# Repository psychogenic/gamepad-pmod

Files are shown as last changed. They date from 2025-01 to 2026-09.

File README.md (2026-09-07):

# Gamepad PMOD
CH32V003-based 2xSNES-compatible controller interface PMOD

Copyright (C) 2025 Pat Deegan, [psychogenic.com](https://psychogenic.com)

Released as free and open source software under the terms of the GPL (see [LICENSE](./LICENSE))

## Overview 

This simple module allows 1 or 2 SNES controllers to report their state over 3 pins, and is used with my SNES PMOD.  Here's the first prototype:

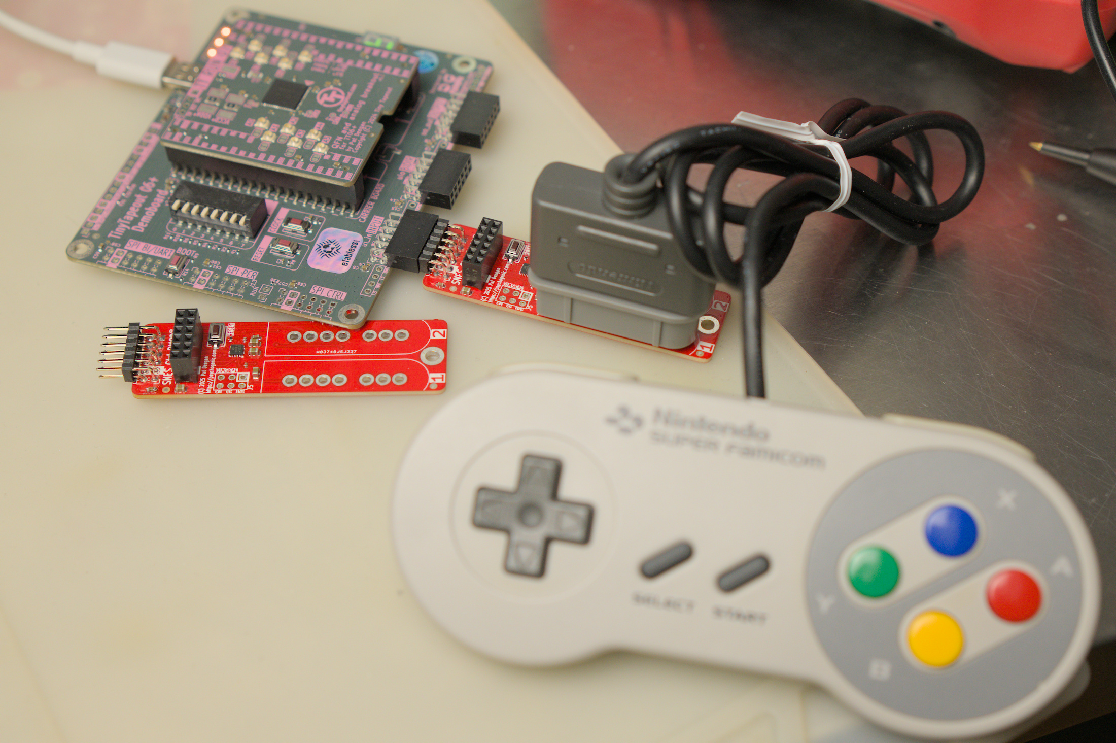
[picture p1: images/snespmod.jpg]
snes pmod


It is a variation on the SNES controller protocol that automatically polls the controllers and reports back values.  The main differences are that the data may be sampled on the rising edge of the clock and the latch happens at the end so it acts like a SIPO (serial in, parallel out) shift register and you can just save the values whenever you see the pulse.  

This allows for using the controllers as read-only devices (i.e. using only input pins on your side) and will send all values in a single transaction (e.g. 24 bits of data in one burst for two controllers).

It may be easily configured (by editing the [config definitions file](src/ch32gamepad_config.h)) to specify:

  * whether to report continuously, only on change and/or with a maximum interval between reports (e.g. only on change but at least every 2 seconds, as is the default configuration);
  
  * the number of controllers (1 or 2);
  
  * the PMOD pins to report back on;
  
  * the bitrate at which these reports are sent;

## Using the gamepad in projects

A [verilog module](verilog/) is provided that makes inclusion in projects simple.  Include the [gamepad_pmod.v](verilog/gamepad_pmod.v) source file in your build and, somewhere in your project, instantiate one of 

	* gamepad_pmod_dual -- to support two controllers, or
	
	* gamepad_pmod_single -- to only support a single controller

You then feed the gamepad module the input data, clock and latch from the outside world and from there you receive information about which buttons are pressed at any time.  

More information and basic samples are in the [verilog directory](verilog/).

A nice example of an implementation using this module is Uri's [2048 game](https://github.com/urish/tt10-2048-game).

## Reading the gamepad from micropython

Though it is designed for use with FPGA/ASIC projects, the reports from controller(s) may also be read on an RP2040 (e.g. the [Tiny Tapeout demoboard](https://github.com/tinyTapeout/tt-demo-pcb)) using code like the sample in [gamepad_reader.py](micropython/gamepad_reader.py).

## Hardware

This code all runs on a simple PMOD that's little more than a CH32V003 and headers to connect to the controllers and PMOD.

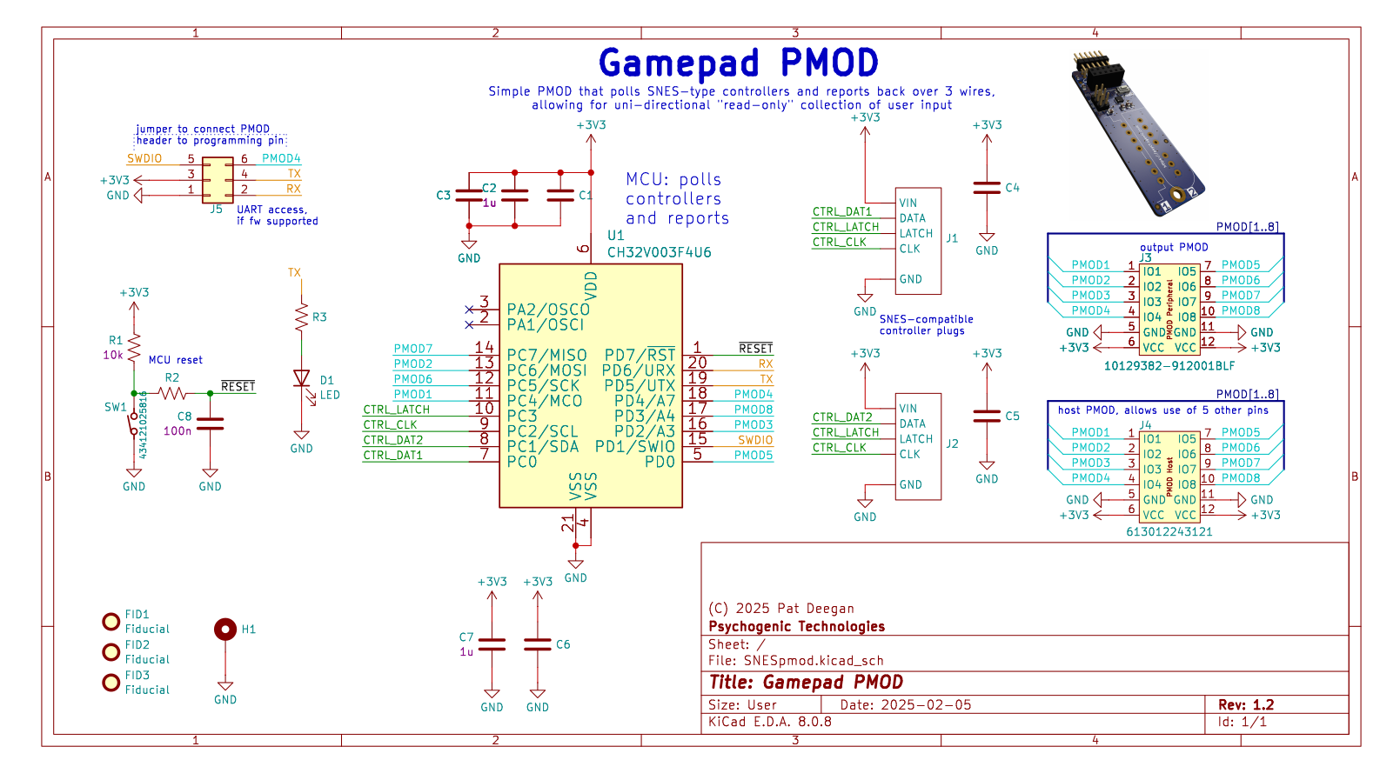
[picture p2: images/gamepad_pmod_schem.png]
schematic


The CH32V polls the controllers as per the standard method for these controllers and, on change or timeout, shoots data out through the peripheral PMOD header, as described in "protocol" below.

It also includes:

  * a PMOD host header, so you could in theory leverage the 5 unused input pins using another PMOD
  
  * an extra 2x3 100 mil header that allows you to jumper the PMOD IO4 into the SWDIO pin, to allow for programming through the PMOD header.
  
The complete project is available under [hardware/GamepadPMOD](hardware/GamepadPMOD).

## Protocol

Reports are sent in the following manner, by default over 3 pins:

  * latch; 
  
  * clock; and
  
  * data

Sample waveform, one controller disconnected, the other holding 3 buttons:

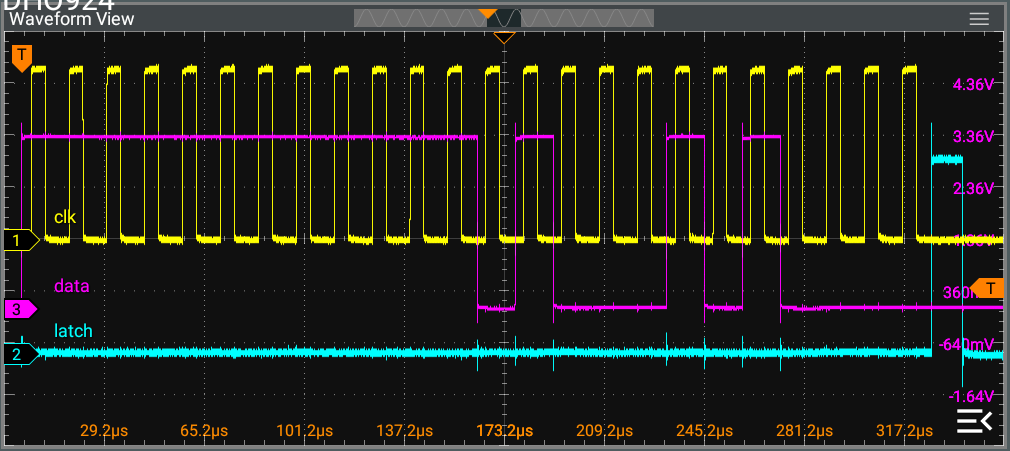
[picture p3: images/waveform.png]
report waveform


A disconnected controller reports all 1s, which includes impossible combinations (e.g. up and down at the same time), and lets us detect controller presence.

Data will be asserted on the data line prior to the clock going high and remain valid past when the clock goes low.  After all bits are sent, latch pulses high.

Each bit will be sent in turn, for each controller, in the following order:

  1. B
  
  2. Y
  
  3. select
  
  4. start
  
  5. up
  
  6. down
  
  7. left
  
  8. right
  
  9. A
  
  10. X
  
  11. L
  
  12. R

With a HIGH value indicating the relevant button is pressed.

## Default TT Configuration

The default setup we'll use for [Tiny Tapeout](https://tinytapeout.com) is:

  *  100kHz clock rate, so that even slowish projects can leverage the input;
  
  *  Latch on PMOD IO5 (*ui_in[4]* on the demoboards, PMODs _aren't_ 0-indexed);
  
  *  Clock on PMOD IO6 (*ui_in[5]*);
  
  *  Data on PMOD IO7 (*ui_in[6]*);
  
  *  2 controllers, i.e. 24 bits of data before the latch pulses; and
  
  *  report-on-change but with a maximum interval between bursts of 1 second (minimum interval is about 1.66ms, or a 600Hz rate for reports, like the SNES console)

### Note on latency and clock domains

Though the SNES consoles only polled at 60Hz, nicely sync'ed to the framerate, if you're a speedrunner you could hit some issues if we do the same, as the PMOD isn't synchronized with the system clock.

After discussion with the community and tests with both el-cheapo chinese controllers and an old famicom thing from the 90s, I'm 10x-ing the controller polling rate to 600Hz.  This doesn't actually impact the rate at which the controllers are clocked, it's just that it happens more often and doesn't seem to cause issue.

From the actual SNES controller perspective, the interaction looks like this:

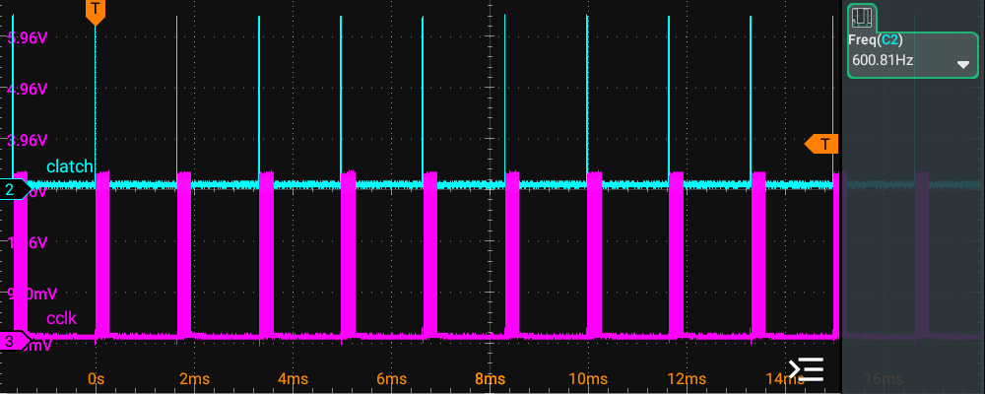
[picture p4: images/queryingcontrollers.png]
snes controller polling


You can see that, on that side, the latch signal comes before the burst of clocking and it's being polled at just around 600Hz.

Since the clocks in projects are independent from the moment at which reports can arrive, its best to do some cleaning for clock domain crossing to ensure stability.

Best and easiest thing is just to use the [gaming_pmod sample module](https://github.com/psychogenic/vga-playground/blob/gaming-pmod/src/examples/gaming/gaming_pmod.v#L109), which handles this.

If you're looking to roll your own, in verilog this would look like classic synchronizer patterns, e.g.

```
reg [1:0] pmod_data_sync;
always @(posedge clk) begin
  if (~rst_n) begin
    pmod_data_sync  <= 2'b0;
  end else begin
    pmod_data_sync  <= {pmod_data_sync[0], pmod_data};
  end
end
```

Whereas with Amaranth, it's little more than using the [FFSynchronizer](https://amaranth-lang.org/docs/amaranth/v0.3/stdlib/cdc.html)

```
FFSynchronizer(i=pmod_data, o=pmod_data_sync)
```

## Building

A selection of pre-compiled firmware is available in [firmware](./firmware), but you may want to build yourself...

To do so, you'll need the awesome [ch32v003fun](https://github.com/cnlohr/ch32v003fun) SDK, by [cnlohr](https://github.com/cnlohr), which is already included here as a submodule.  To ensure you have that, you can do

```
git submodule update --init --recursive
```

from the top level directory.

Then simply (optionally) hook-up a supported programmed to the target module and

```
cd src
make
```

That should be it.

## Updating firmware

The CH32V firmware may be updated using a suitable programmer.  However, to assist the production run and to make future updates easy I updated the pico_ch32v003_prog to use less memory and burn firmware.

The fork and a sample using it is available on [gamepad-update](https://github.com/psychogenic/gamepad-update/tree/main/src).

Adding a jumper between the two top pins on the 6-pin header, between PRJ and SWIO:

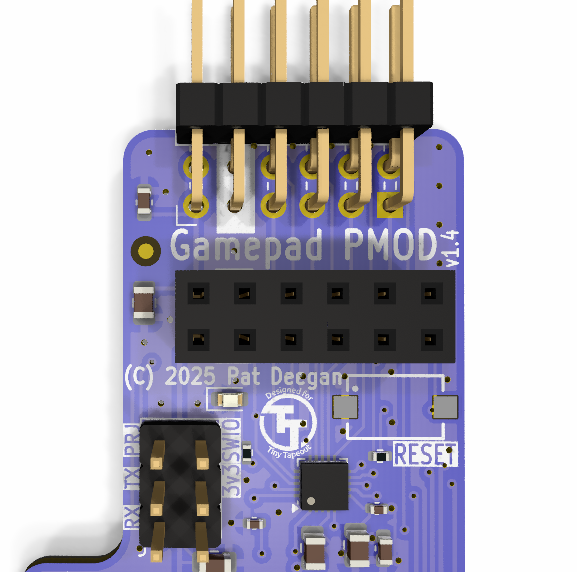
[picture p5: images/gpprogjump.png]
programming header


will connect PMOD IO4 to the programming pin and allow the RP2040 on the demoboard to write new firmware.

## Assembly

These controller connectors aren't actually meant to be used this way.  In order to provide a bit of stability, we 3D print little feet:

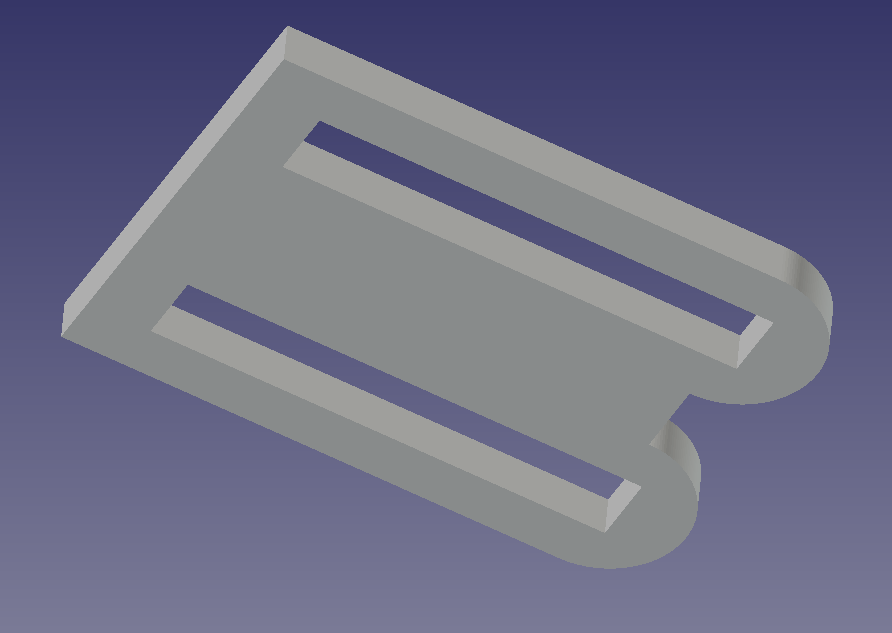
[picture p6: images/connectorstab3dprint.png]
stabilizer foot


The STL file for this is [hardware/gamepad-footstabv1p0-tol2.stl](./hardware/gamepad-footstabv1p0-tol2.stl)

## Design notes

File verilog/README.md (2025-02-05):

# Gamepad PMOD verilog module

This module provides plug & play support for the gamepad pmod in your projects

Include the [gamepad_pmod.v](gamepad_pmod.v) source file in your build and, somewhere in your project, instantiate one of 

	* gamepad_pmod_dual -- to support one or two controllers, or
	
	* gamepad_pmod_single -- to only support a single controller

You then feed the gamepad module the input data, clock and latch from the outside world and from there you receive information about which buttons are pressed at any time.  The module outputs split up the buttons such that they have reasonable names and they will be HIGH as long as the button in question is held pressed by the user.

## single controller support

If you want to save on bits, you may use the `gamepad_pmod_single`.  This only latches in the last 12 bits of data, so might give you a little bit of space saving in term of flops but you'll be losing data for one player if two controllers are physically connected.

It provides this interface

```
module gamepad_pmod_single (
    input wire rst_n,
    input wire clk,
    input wire pmod_data,
    input wire pmod_clk,
    input wire pmod_latch,

    output wire b,
    output wire y,
    output wire select,
    output wire start,
    output wire up,
    output wire down,
    output wire left,
    output wire right,
    output wire a,
    output wire x,
    output wire l,
    output wire r,
    output wire is_present
);
```

Other than the clock and reset, it takes in three wires from the PMOD for data, clock and latch.  The outputs are split as individual bits, `start`, `left`, `right` etc.  These will remain HIGH so long as the button is held.

In addition to the standard controller buttons, there is an `is_present` field to let you know whether there's a controller connected.

## dual controller support

At the cost of shuffling 12 extra bits around, you can support up to two controllers using `gamepad_pmod_dual`.  This module takes the same inputs as the single version, and basically provides the same API, but instead of single wires for the buttons, each is two bits wide, so you get the status of each controller indexed within (e.g. if  `is_present[0]` and `is_present[1]` are both HIGH, you have two controllers connected).

The module API is thus:

```
module gamepad_pmod_dual (
    input wire rst_n,
    input wire clk,
    input wire pmod_data,
    input wire pmod_clk,
    input wire pmod_latch,

    output wire [1:0] b,
    output wire [1:0] y,
    output wire [1:0] select,
    output wire [1:0] start,
    output wire [1:0] up,
    output wire [1:0] down,
    output wire [1:0] left,
    output wire [1:0] right,
    output wire [1:0] a,
    output wire [1:0] x,
    output wire [1:0] l,
    output wire [1:0] r,
    output wire [1:0] is_present
);
```
 
## Including in a project

Including in a project is just a question of instantiating a module to wire it up and then acting according to button presses reported.  It might look something like:

```
module my_top (
    input  wire [7:0] ui_in,    // Dedicated inputs
    output wire [7:0] uo_out,   // Dedicated outputs
    input  wire [7:0] uio_in,   // IOs: Input path
    output wire [7:0] uio_out,  // IOs: Output path
    output wire [7:0] uio_oe,   // IOs: Enable path (active high: 0=input, 1=output)
    input  wire       ena,      // always 1 when the design is powered, so you can ignore it
    input  wire       clk,      // clock
    input  wire       rst_n     // reset_n - low to reset
);

  // Gamepad Pmod support
  wire gamepad_pmod_latch = ui_in[4];
  wire gamepad_pmod_clk = ui_in[5];
  wire gamepad_pmod_data = ui_in[6];
  wire gamepad_is_present;
  wire gamepad_left;
  wire gamepad_right;
  wire gamepad_up;
  wire gamepad_down;
  wire gamepad_start;
  wire gamepad_select;

  gamepad_pmod_single gamepad_pmod (
      // Inputs:
      .clk(clk),
      .rst_n(rst_n),
      .pmod_latch(gamepad_pmod_latch),
      .pmod_clk(gamepad_pmod_clk),
      .pmod_data(gamepad_pmod_data),

      // Outputs:
      .is_present(gamepad_is_present),
      .left(gamepad_left),
      .right(gamepad_right),
      .up(gamepad_up),
      .down(gamepad_down),
      .start(gamepad_start),
      .select(gamepad_select)
  );
  // do things when buttons are pressed and gamepad_* go high.
  
endmodule

```

A nice example of an implementation using this module is Uri's [2048 game](https://github.com/urish/tt10-2048-game).

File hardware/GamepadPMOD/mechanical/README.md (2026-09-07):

# Dual straight-SNES connector gap filler

`dual_snes_connector_gap_filler.stl` is one consolidated two-piece set that
supports **both** straight SNES connectors on one Gamepad PMOD.

## Measured fit

The dimensions come from `SNES_Connector_Straight_Master_Assy.stp`, which
matches the board's seven-pin 4/4/4/6.5/4/4 mm pitch:

| Feature | STEP Z | Result |
|---|---:|---:|
| PCB seating datum / pedestal bottom | -14.60 mm | — |
| Broad housing underside | -11.40 mm | — |
| Nominal housing-to-PCB gap | — | **3.20 mm** |
| Filler with vertical clearance | — | **3.10 mm** |

The matching
[vertical KiCad footprint](https://github.com/shuki25/kicad-custom-library/blob/master/footprints/SNES_Controller_Port_Vertical.kicad_mod)
applies a +14.60 mm Z offset to the STEP model. This places the pedestal
bottom at the PCB top surface and confirms the mounting datum used above.

The earlier 0.50 mm estimate from a different right-angle connector model does
not apply to this straight connector.

## Design and installation

Each connector's central semistadium-shaped pedestal reaches the PCB, leaving
a 3.20 mm-high ring-shaped cavity under the wider housing. The filler reproduces
the STEP model's exact outer and pedestal profiles with 0.15 mm horizontal
clearance. Matching halves for J1 and J2 are joined across the 4.50 mm space
between their housings by a bridge spanning the complete **32.25 mm straight
section** of the support profile. The result is split along the connector
pin-row direction into front and rear consolidated pieces. The two bridge
sections meet at the split without overlap, retaining post-assembly
installation while giving each half the widest possible load path.

Print flat without supports. Insert one half from each long side of the
connector until its inner profile seats around the central pedestal. A small
spot of flexible adhesive can retain a loose fit; keep adhesive away from
solder joints. Confirm the 3.20 mm gap on a production connector before batch
printing because STEP models do not define manufacturing tolerance.

## Files

- `dual_snes_connector_gap_filler.FCStd` — consolidated FreeCAD model
- `dual_snes_connector_gap_filler.step` — two-piece dual-connector solid
- `dual_snes_connector_gap_filler.stl` — one complete set per PCB
- `dual_snes_connector_gap_filler_kicad.step` — J1-local KiCad model
- `dual_snes_connector_gap_filler.py` — FreeCAD generator
- `GamepadPMOD_board.step` — PCB exported from the Elecrow branch
- `GamepadPMOD_dual_connector_assembly.FCStd` — visual fit assembly
- `GamepadPMOD_dual_connector_assembly.step` — portable assembly
- `GamepadPMOD_dual_connector_assembly.png` — top verification render
- `GamepadPMOD_dual_connector_assembly_side.png` — gap/profile render
- `render_assembly.ps1` — regenerate all models and renders

The design dimensions are collected at the top of the generator and recorded
in the `.FCStd` `Parameters` spreadsheet. Edit the generator and run:

```powershell
& 'C:\Program Files\FreeCAD 1.0\bin\freecadcmd.exe' dual_snes_connector_gap_filler.py
```

The visual assembly uses the Elecrow branch placements J1 `(22.50, 61.37,
-90°)` and J2 `(39.00, 61.37, -90°)`, the supplied connector STEP, and the
KiCad-exported board STEP. The board also references the connector STEP on J1
and J2 and the J1-local dual filler STEP, so KiCad's native 3D renderer checks
the same placements used by fabrication:

```powershell
.\render_assembly.ps1
```

The script exports the fully populated KiCad STEP and verifies that the STEP
pin centres exactly match all 14 PCB drills:

| Connector | Pin-centre X | Pin-centre Y |
|---|---:|---|
| J1 | 22.50 mm | 61.37, 65.37, 69.37, 73.37, 79.87, 83.87, 87.87 mm |
| J2 | 39.00 mm | 61.37, 65.37, 69.37, 73.37, 79.87, 83.87, 87.87 mm |

It also rejects filler-to-PCB or filler-to-connector intersections.

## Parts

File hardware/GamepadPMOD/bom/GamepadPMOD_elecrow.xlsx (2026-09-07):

*Reference | *Manufacturer Part number | *QTY | *Original | Description | Purchase Link
C1, C4, C5, C6 | CL21A106KOQNNNE | 4 |  | 10u/35V | https://www.digikey.com.au/en/products/result?keywords=CL21A106KOQNNNE
C2, C7 | CL10A105KB8NNNC | 2 |  | 1u | https://www.digikey.com.au/en/products/result?keywords=CL10A105KB8NNNC
C3, C8 | CL05B104KO5NNNC | 2 |  | 100n | https://www.digikey.com.au/en/products/result?keywords=CL05B104KO5NNNC
D1 | APT1608SURCK | 1 |  | Red LED, 630 nm, 0603 (1608 metric) | https://www.digikey.com.au/en/products/detail/kingbright/APT1608SURCK/386438
J1, J2 |  | 2 |  | SFC connector VERT
J3 | 10129382-912001BLF | 1 |  | 10129382-912001BLF | https://www.digikey.com.au/en/products/result?keywords=10129382-912001BLF
J4 | 613012243121 | 1 |  | 613012243121 | https://www.digikey.com.au/en/products/result?keywords=613012243121
J5 |  | 1 |  | Conn_02x03_Odd_Even
R1 | RC0402FR-0710KL | 1 |  | 10k | https://www.digikey.com.au/en/products/result?keywords=RC0402FR-0710KL
R2 | RC0402FR-071KL | 1 |  | 1k | https://www.digikey.com.au/en/products/result?keywords=RC0402FR-071KL
R3 | RC0402FR-07200RL | 1 |  | 200R | https://www.digikey.com.au/en/products/result?keywords=RC0402FR-07200RL
SW1 | 434121025816 | 1 |  | 434121025816 | https://www.digikey.com.au/en/products/result?keywords=434121025816
U1 | CH32V003F4U6 | 1 |  | CH32V003F4U6 | https://www.digikey.com.au/en/products/result?keywords=CH32V003F4U6

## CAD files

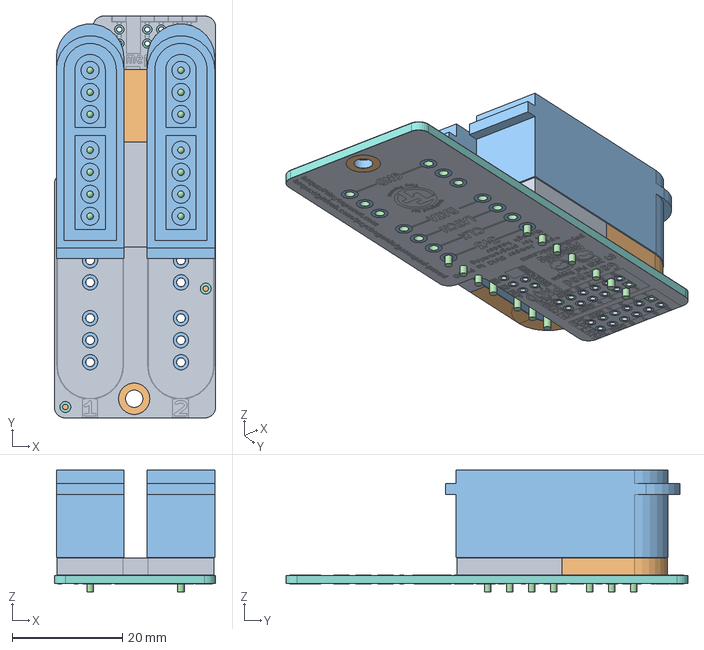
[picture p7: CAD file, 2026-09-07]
hardware/GamepadPMOD/mechanical/GamepadPMOD_dual_connector_assembly.step
29.3 x 73.0 x 22.1 mm

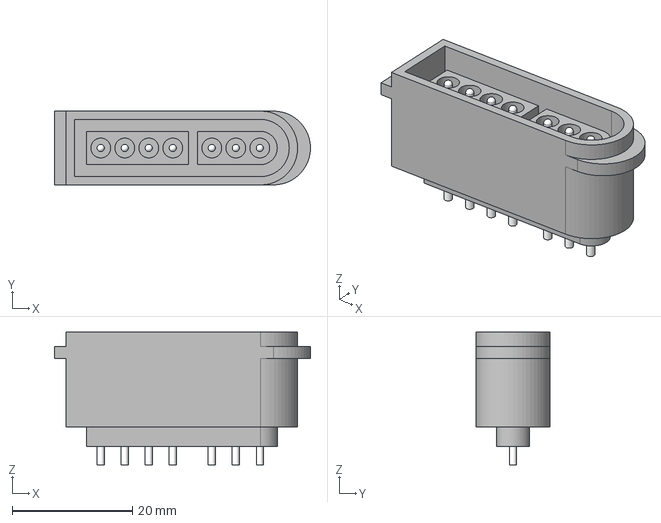
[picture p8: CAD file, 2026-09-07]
hardware/GamepadPMOD/mechanical/SNES_Connector_Straight_Master_Assy.stp
42.6 x 12.3 x 22.1 mm

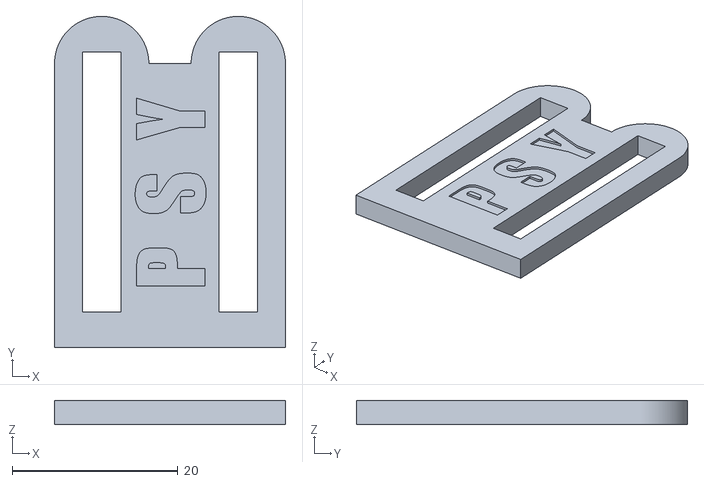
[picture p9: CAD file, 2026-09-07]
hardware/gamepad-footstabv1p0-tol2.stl
27.9 x 40.0 x 2.90

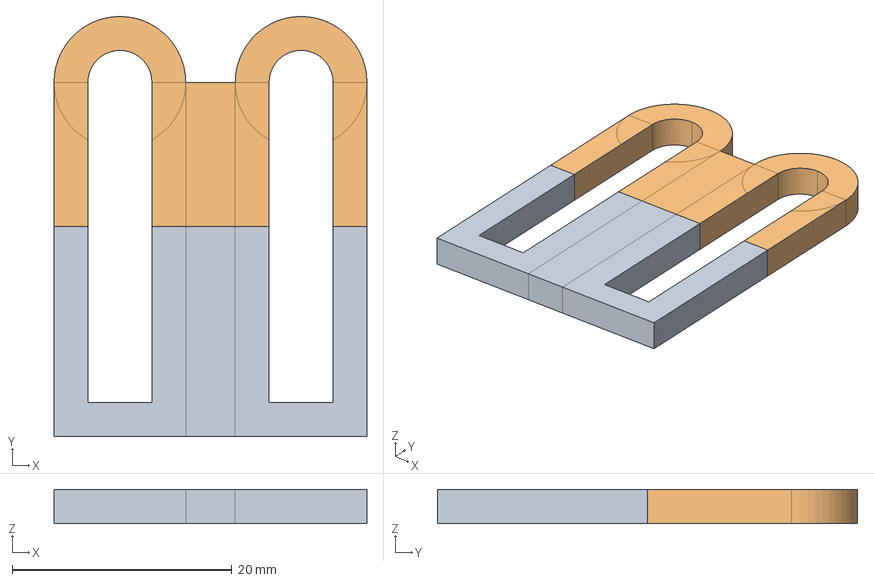
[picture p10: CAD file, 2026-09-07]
hardware/GamepadPMOD/mechanical/dual_snes_connector_gap_filler.step
28.5 x 38.2 x 3.10 mm

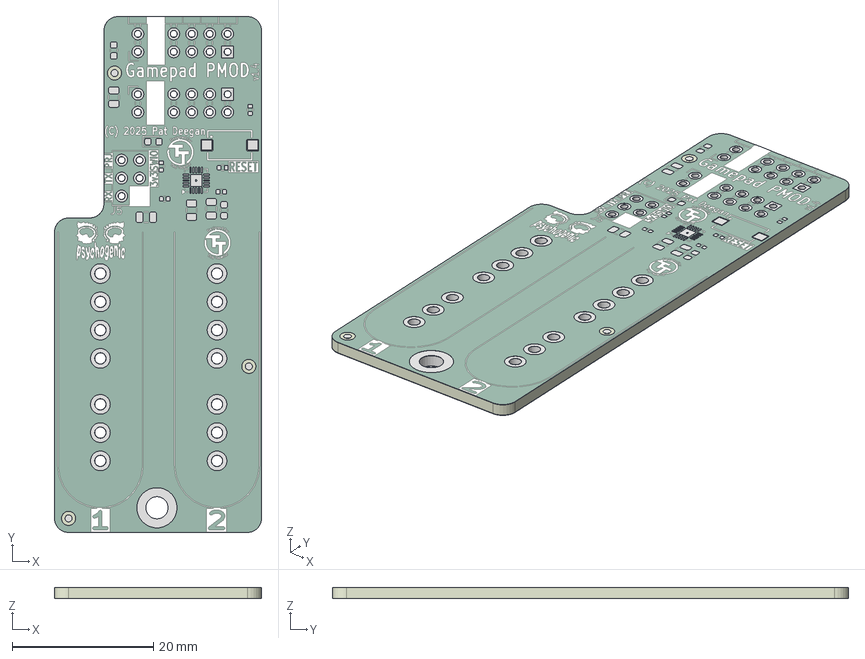
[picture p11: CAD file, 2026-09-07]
hardware/GamepadPMOD/mechanical/GamepadPMOD_board.step
29.3 x 73.0 x 1.66 mm
GamepadPMOD_pad
GamepadPMOD_silkscreen x 2
GamepadPMOD_soldermask x 2
GamepadPMOD_PCB

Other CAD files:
hardware/GamepadPMOD/mechanical/dual_snes_connector_gap_filler_kicad.step
hardware/GamepadPMOD/mechanical/GamepadPMOD_dual_connector_assembly.FCStd
hardware/GamepadPMOD/mechanical/dual_snes_connector_gap_filler.FCStd
hardware/GamepadPMOD/mechanical/dual_snes_connector_gap_filler.stl

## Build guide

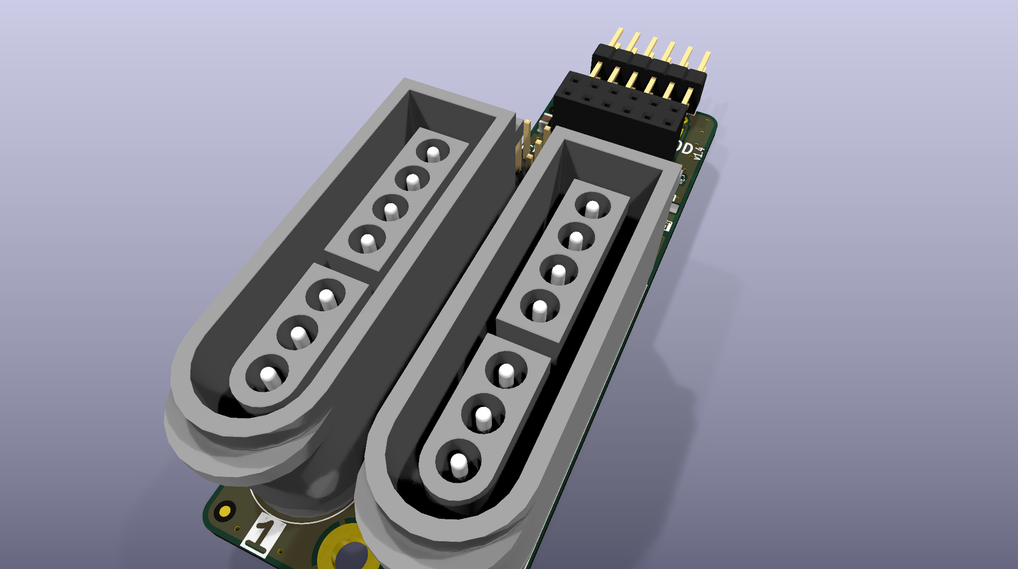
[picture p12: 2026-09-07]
hardware/GamepadPMOD/mechanical/GamepadPMOD_dual_connector_assembly.png

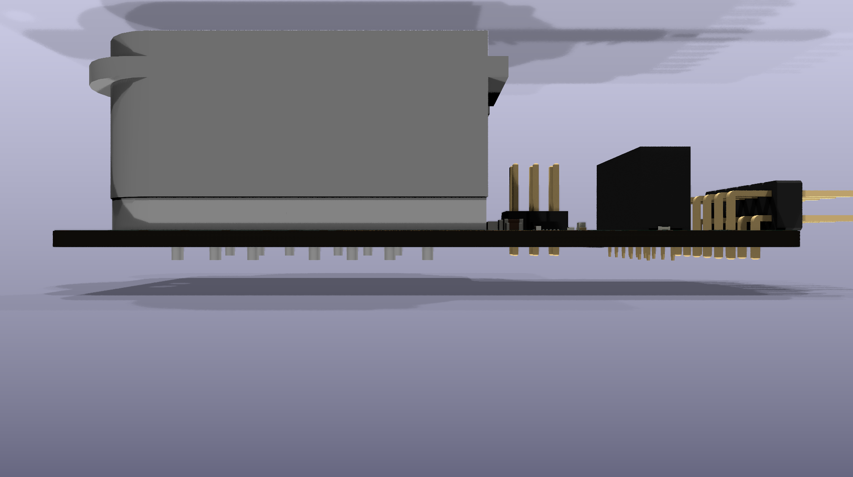
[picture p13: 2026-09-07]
hardware/GamepadPMOD/mechanical/GamepadPMOD_dual_connector_assembly_side.png

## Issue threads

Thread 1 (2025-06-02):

Connecting gamepad-pmod with TinyTapeout 06+ Demoboard

pongsagon, 2025-06-02:
Hi Pat,

First of all, thanks for your work on gamepad-pmod.  It is very cool to be able to use SNES gamepad with the ASIC project.

If I connect gamepad-pmod with TinyTapeout 06+ Demoboard **before** plugin usb-c,
the https://commander.tinytapeout.com/ will not be able to detect Shuttle version and cannot do anything.
If I connect gamepad after plugin usb-c, it would work perfectly.  Is this normal?

Unfortunately, there is no TT07 demo that I can try the gamepad.
I would like to use your gamepad-pmod in my next TinyTapeout project.
Do you think it would behave the same if I try it with my ASIC prototype on Basys3 FPGA board.

Cheers,
Matt

urish, 2025-06-21:
Yes, the Gamepad Pmod uses the same ui_in input pins that the Demoboard firmware uses for reading the ROM from the chip. So if it's plugged to the demoboard on startup, it can interfere with the detection.

You can use the force_shuttle option in config.ini to skip the detection: https://tinytapeout.com/guides/get-started-demoboard/#troubleshooting

Closed 2025-06-22.

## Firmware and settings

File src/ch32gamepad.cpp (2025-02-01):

/*
 * ch32gamepad.cpp
 * Main driver for the module.
 *
 *  Created on: Jan 19, 2025
 *      Author: Pat Deegan
 *    Copyright (C) 2025 Pat Deegan, https://psychogenic.com
 *    
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
 *    You should have received a copy of the GNU General Public License
 *    along with this program.  If not, see <https://www.gnu.org/licenses/>.
 */

#include "ch32gamepad_includes.h"
#include "controllerset.h"
#include "reportport.h"
#include "PMODport.h"
#include <stdio.h>

// define TEST_PMOD /* used to cycle through PMOD pins and do QA, ignore */
#ifdef TEST_PMOD
void testPMOD();
#endif


#define DRIVER_BUSY_ELSEWHERE_FUDGE_US		90
#define CONTROLLER_POLL_TIME_US				((CONTROLLER_STATUS_NUM_BITS*CONTROLLER_CLOCK_PERIOD_US) \
												+ (CONTROLLER_LATCH_PULSE_WIDTH_US+CONTROLLER_LATCH_PULSE_WIDTH_US \
												+   DRIVER_BUSY_ELSEWHERE_FUDGE_US))
#define CONTROLLER_POLLING_INTERVAL_US		((1000000UL/(uint16_t)CONTROLLER_POLLING_INTERVAL_HZ) - CONTROLLER_POLL_TIME_US)
#define CONTROLLER_POLLING_INTERVAL_MS		(CONTROLLER_POLLING_INTERVAL_US/1000)
#define MAX_SKIPPED_REPORTS ((int)(MINIMUM_REPORT_INTERVAL_SECONDS * CONTROLLER_POLLING_INTERVAL_HZ))

#define LED_OFF() funDigitalWrite(PIN_LED, FUN_LOW);
#define LED_ON()  funDigitalWrite(PIN_LED, FUN_HIGH);
int main() {
	SystemInit();

	GPIO_port_enable(GPIO_port_C);
	GPIO_port_enable(GPIO_port_D);

	DEBUG_OUT("CH32SNES boot...");

	funPinMode(PIN_LED, CONTROLLER_PIN_DEFAULTSETTINGS_OUTPUT);
	LED_ON();


#ifdef TEST_PMOD
	DEBUG_OUT("PMOD test running...\n");
	// will get stuck in this infinite loop
	testPMOD();
#endif


	SNES::ControllerSet controllers(PIN_CONTROLLERS_LATCH,
			PIN_CONTROLLERS_CLOCK,
			PIN_CONTROLLERS_DATA1,
			PIN_CONTROLLERS_DATA2);


	PMOD::ReportPort reporter(PIN_REPORT_LATCH ,
			PIN_REPORT_CLOCK,
			PIN_REPORT_DATA);



	controllers.begin();
	reporter.begin();

	for (uint8_t i=0; i<4; i++) {
		LED_ON();
		Delay_Ms(50);
		LED_OFF();
		Delay_Ms(50);
	}

	#if PIN_INCHANGE_LED_ENABLE
		uint32_t ledOnUntil = 0;
	#endif

	DEBUG_OUT("started\n");

	uint16_t numSkipped = 0;
	uint16_t tickCount = 0;
	while (true) {
		tickCount++;
		bool haveInData = controllers.poll();
		if (haveInData || !(REPORT_ONLY_ON_CHANGE)) {
			const SNES::ControllerSet::StateBits & curstate = controllers.state();

			#if PIN_INCHANGE_LED_ENABLE
				if (haveInData) {
					ledOnUntil = tickCount + (PIN_INCHANGE_LED_MS/CONTROLLER_POLLING_INTERVAL_MS) + 1;
				}
			#endif /* PIN_INCHANGE_LED_ENABLE */

			reporter.send(curstate.state, curstate.num);
			numSkipped = 0;
		} else {

			if (numSkipped < MAX_SKIPPED_REPORTS) {
				numSkipped ++;
			} else {
				const SNES::ControllerSet::StateBits & curstate = controllers.state();
				reporter.send(curstate.state, curstate.num);
				numSkipped = 0;
			}
		}
		#if PIN_INCHANGE_LED_ENABLE
		if (ledOnUntil) {
			if (tickCount >= ledOnUntil) {
				ledOnUntil = 0;
				funDigitalWrite(PIN_LED, FUN_LOW);
			} else {
				funDigitalWrite(PIN_LED, FUN_HIGH);
			}
		}
		#endif /* PIN_INCHANGE_LED_ENABLE */
		Delay_Us(CONTROLLER_POLLING_INTERVAL_US);
	}
}


#ifdef TEST_PMOD
void testPMOD() {
	PMOD::Port pmod(PIN_PMOD_IO1, PIN_PMOD_IO2, PIN_PMOD_IO3, PIN_PMOD_IO4,
					PIN_PMOD_IO5, PIN_PMOD_IO6, PIN_PMOD_IO7, PIN_PMOD_IO8);
	pmod.begin();
	while (true) {
		for (uint8_t i=0; i<8; i++) {
			uint8_t v = 1 << i;
			pmod.write(v);

			DEBUG_OUT("Wrote %u, read %u\n", v, pmod.read());
			Delay_Ms(20);
		}
	}
}
#endif

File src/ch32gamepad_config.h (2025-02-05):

/*
 * ch32gamepad_config.h
 * Configuration for SNES controller PMOD.
 *
 * Edit this file to set which pins are used for reporting data on the PMOD,
 * the timing and behaviour of reports and more.
 *
 *  Created on: Jan 19, 2025
 *      Author: Pat Deegan
 *    Copyright (C) 2025 Pat Deegan, https://psychogenic.com
 *    
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
 *    You should have received a copy of the GNU General Public License
 *    along with this program.  If not, see <https://www.gnu.org/licenses/>.
 */

#ifndef CH32SNES_CONFIG_H_
#define CH32SNES_CONFIG_H_


// makes PIN_PMOD_IO* and PIN_CONTROLLERS_* available, mapped to schem
#include "ch32gamepad_pinout.h"

/*
 * Map PIN_REPORT_* using the PIN_PMOD_IO[1-8] of your choice.
 * The official TinyTapeout PMOD will be using ui_in[6:4],
 * so PMOD IO 5, 6 and 7--the default here.
 */
#define PIN_REPORT_LATCH			PIN_PMOD_IO5
#define PIN_REPORT_CLOCK			PIN_PMOD_IO6
#define PIN_REPORT_DATA				PIN_PMOD_IO7




/* REPORT_ONLY_ON_CHANGE: send reports only
 * if value has changed (1) or always (0)
 */
#define REPORT_ONLY_ON_CHANGE			1

/*
 * MINIMUM_REPORT_INTERVAL_SECONDS
 * If REPORT_ONLY_ON_CHANGE, a MINIMUM_REPORT_INTERVAL_SECONDS will
 * still shoot out a report this often.  May be fractional.
 */
#define MINIMUM_REPORT_INTERVAL_SECONDS		1

/*
 * CONTROLLERSET_NUM_CONTROLLERS: number of controllers to report for.
 * May be 1 or 2.  A total of CONTROLLERSET_NUM_CONTROLLERS*12 bits of
 * report will be sent after each latch.
 */
#define CONTROLLERSET_NUM_CONTROLLERS		2


/*
 * Reporter reports data back to you over PMOD header
 * These values set the baudrate of everything, namely:
 *  - width of the "latch" (this is a new data block) pulse
 *  - time delay after pulse to clock out data (may be 0)
 *  - the period of the clocked data
 *  - an optional delay after data assertion to allow for
 *    setup time prior to clocking.
 * all in microseconds.
 */
#define REPORTER_LATCH_PULSE_WIDTH_US			10
#define REPORTER_LATCH_PULSE_POSTDELAY_US		0
#define REPORTER_CLOCK_PERIOD_US				8
#define REPORTER_DATA_SETUP_DELAY_US			2

#define REPORTER_SHIFT_SINGLE_CTRL_PRESENT_TO_LAST_BITS


/*
 * PIN_INCHANGE_LED*
 * Enable LED blink on input change, and set
 * the time it's on (approx)
 */
#define PIN_INCHANGE_LED_ENABLE		1
#define PIN_INCHANGE_LED_MS			50


/*
 * CH32SNES_DEBUG_LEVEL 0 - 2, 0 == disabled, 2 == verbose
 * With a programmer connected, see debug using
 *  ch32v003fun/minichlink/minichlink -T
 *
 */
#define CH32SNES_DEBUG_LEVEL	2



/*
 * SNES controlle protocol defaults.
 * 60Hz poll rate and these values seem to be the values used
 * by consoles.
 * Note the _MS (millis) and _US (micros) suffixen.
 */
#define CONTROLLER_POLLING_INTERVAL_HZ			600
#define CONTROLLER_LATCH_PULSE_WIDTH_US			12
#define CONTROLLER_LATCH_PULSE_POSTDELAY_US		6
#define CONTROLLER_CLOCK_PERIOD_US				12

/*
 * CONTROLLER_RESPONSE_INVERTED -- 1==logic low for press
 */
#define CONTROLLER_RESPONSE_INVERTED			1


/*
 * We clock out 16 bits from controllers, but high 4 are always 1,
 * only 12 bits contain data
 */
#define CONTROLLER_STATUS_NUM_BITS				16
#define CONTROLLER_STATUS_NUM_BITS_TO_REPORT	12

/*
 * Default config for I/O. Using pull-ups on inputs by default.
 */
#define CONTROLLER_PIN_DEFAULTSETTINGS_INPUT 	(GPIO_Speed_In | GPIO_CNF_IN_PUPD)
#define CONTROLLER_PIN_DEFAULTSETTINGS_OUTPUT 	(GPIO_Speed_10MHz | GPIO_CNF_OUT_PP)


#endif /* CH32SNES_CONFIG_H_ */

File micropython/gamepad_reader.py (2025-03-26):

'''
A nifty little PIO class to read the gamepad 
data packets and a demonstration test.

@author: Pat Deegan
@copyright: Copyright (C) 2025 Pat Deegan, https://psychogenic.com
'''


GPLatchPin = 17
GPClockPin = 18
GPDataPin = 19

DEBUG_OUT_PINSTART = 21

from machine import Pin
import utime
import micropython
import rp2
from rp2 import PIO, StateMachine
from array import array



# messy PIO program to read in data
@rp2.asm_pio(in_shiftdir=PIO.SHIFT_LEFT,
             sideset_init=(PIO.OUT_LOW, PIO.OUT_LOW, PIO.OUT_LOW, PIO.OUT_LOW))
def sipo_reader():
    wrap_target()
    
    push(noblock).side(0b000)  # Reset ISR
    
    label("poll_loop")
    jmp(pin, "send_data")       # Pins are 0b[DAT CLK LATCH] 
    mov(x, isr)  # stash isr
    mov(isr, null) # zero isr
    in_(pins, 1)  # pull CLCK input into isr
    mov(y, isr) # stash current CLOCK
    nop()
    mov(isr, x) # restor isr
    nop()
    # push(block)
    # y (CLK) is either HIGH -- time to sample, or LOW wait some more
    jmp(not_y, "poll_loop") # CLK IS LOW, wait for HIGH or LATCH
    #CLOCK IS HIGH
    # get sample
    
    mov(x, isr) # stash ISR
    mov(isr, null)
    in_(pins, 2) # sampled CLOCK (HIGH) + DATA into ISR
    nop()
    mov(y, isr) # sample CLOCK + DAT
    nop()
    mov(isr, x) # restore accum ISR
    nop()
    set(x, 0b01) # DAT LOW + CLK HIGH
    
    jmp(x_not_y, "add_dat_high")  # not equal, so DAT HIGH
    label("add_dat_low")
    set(x, 0) # didn't jump, so DAT bit is LOW
    jmp("wait_clock_low")
    
    
    label("add_dat_high")
    set(x, 1) # jumped here, so DAT is HIGH
    jmp("wait_clock_low")
    
    label("wait_clock_low")
    in_(x, 1) # DAT bit stashed in X, add that to ISR
    # wait(0, pins, 0)  # WAIT FOR CLOCK LOW -- this fails?  dunno why
    # using hard coded pin wait which does work
    wait(0, gpio, GPClockPin)  # WAIT FOR CLOCK LOW
    jmp("poll_loop")
    

    label("send_data")
    push(noblock)               # Send ISR
    wait(0, gpio, GPLatchPin)
    mov(isr, null) # clear ISR
    jmp("poll_loop")
    wrap()
    
    
class SIPO:
    def __init__(self, dat_pin=GPDataPin, clk_pin=GPClockPin, 
					latch_pin=GPLatchPin, max_bits=32):
        # Configure StateMachine with specific pins
        
        self.clk_pin = Pin(clk_pin, Pin.IN)
        self.latch_pin = Pin(latch_pin, Pin.IN)
        self.dat_pin = Pin(dat_pin, Pin.IN) 
        
        print(f"LATCH {latch_pin} is {self.latch_pin}: {self.latch_pin.value()}")
        self.sm = StateMachine(6, sipo_reader,
                              in_base=self.clk_pin,  
                              jmp_pin=self.latch_pin,
                              sideset_base=Pin(DEBUG_OUT_PINSTART)) # LATCH pin 
        
        
        
        
        # Buffer for data (32-bit unsigned int)
        self._last_data = 0
        self._cur_data = 0
        self.max_bits = min(max_bits, 32)  # Cap at 32 bits
        
        
        
    def enable(self):
        print("Enabling SIPO PIO reader")
        self.sm.active(1)
    def disable(self):
        print("Disabling SIPO PIO reader")
        self.sm.active(0)

    @property 
    def new_packet(self):
        if self.sm.rx_fifo() > 0:
            self.read()
            return True 
        
        return False
    
    @property 
    def captured_packet(self):
        return self._cur_data
    
    @property 
    def changed_value(self):
        return self._cur_data != self._last_data
    
    def read(self):
        """Read the latest variable-length data"""
        if self.sm.rx_fifo() > 0:  # Check if data is available
            self._last_data = self._cur_data
            self._cur_data = self.sm.get() & ((1 << self.max_bits) - 1)
        return self._cur_data




class ControllerState:
    def __init__(self, raw_val:int):
        self._rawval = raw_val 
        
    @property 
    def present(self):
        return self._rawval != 0xfff 
    
    def as_str(self):
        vals = [
                'B ',
                'Y ',
                'SL',
                'ST',
                'UP',
                'DW',
                'L ',
                'R ',
                'A ',
                'X ',
                'LT',
                'RT'
            ]
        
        vals.reverse()
        
        if not self.present:
            return '     not connected      '
        rv = []
        for i in range(12):
            if self._rawval & (1 << i):
                rv.append(vals[i])
            else:
                rv.append('  ')
        return ''.join(rv)     
    
class PacketReader:
    
    def __init__(self):
        pass 
    
    def states(self, raw_packet_bits:int):
        ctl1 = ControllerState( (raw_packet_bits & 0xfff))
        ctl2 = ControllerState( (raw_packet_bits & (0xfff << 12)) >> 12)
        
        return (ctl1, ctl2)
    



def test_gamepad():
    outval = 0
    tlast = utime.time()
    numPacketsRcvd = 0
    pReader = PacketReader()
    gamepad = SIPO()
    
    gamepad.enable()
    packTime = utime.time()
    while True:
        
        if utime.time() - packTime > 3:
            packTime = utime.time()
            print("\nShould have received packets by now...")
        
        if gamepad.new_packet:
            packTime = utime.time()
            numPacketsRcvd += 1
            if gamepad.changed_value:
                (ctrl1, ctrl2) = pReader.states(gamepad.captured_packet)
                print("\n", numPacketsRcvd, "\t", 
                      ctrl1.as_str(),
                      " | ",
                      ctrl2.as_str(),
                      end='')
            else:
                print('.', end='')
                
if __name__ == '__main__':
	test_gamepad()

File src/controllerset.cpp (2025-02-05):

/*
 * controllerset.cpp
 *
 *  Created on: Jan 19, 2025
 *      Author: Pat Deegan
 *    Copyright (C) 2025 Pat Deegan, https://psychogenic.com
 *    
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
 *    You should have received a copy of the GNU General Public License
 *    along with this program.  If not, see <https://www.gnu.org/licenses/>.
 */

#include "controllerset.h"

namespace SNES {


ControllerSet::ControllerSet(Pin pin_latch, Pin pin_clock,
		Pin data1, Pin data2):
				latch(pin_latch),
				clock(pin_clock)
{
	controllers[0] = Controller(data1);
#if CONTROLLERSET_NUM_CONTROLLERS > 1
	controllers[1] = Controller(data2);
#endif
}

void ControllerSet::begin() {
	for (uint8_t i=0; i<CONTROLLERSET_NUM_CONTROLLERS; i++) {
		controllers[i].begin();
	}

	funPinMode(clock, CONTROLLER_PIN_DEFAULTSETTINGS_OUTPUT);
	funPinMode(latch, CONTROLLER_PIN_DEFAULTSETTINGS_OUTPUT);

}

bool ControllerSet::poll() {
	Controller::Status polled_statii[CONTROLLERSET_NUM_CONTROLLERS] = {0};
	funDigitalWrite(latch, FUN_HIGH);
	Delay_Us(CONTROLLER_LATCH_PULSE_WIDTH_US);
	funDigitalWrite(latch, FUN_LOW);
	Delay_Us(CONTROLLER_LATCH_PULSE_POSTDELAY_US);

	for (uint8_t ctrl=0; ctrl<CONTROLLERSET_NUM_CONTROLLERS; ctrl++) {
		polled_statii[ctrl].rawbits = 0;
	}

	for (uint8_t i=0; i< (CONTROLLER_STATUS_NUM_BITS - 1); i++) {
		// first bit is present after latching
		for (uint8_t ctrl=0; ctrl<CONTROLLERSET_NUM_CONTROLLERS; ctrl++) {
			if (controllers[ctrl].inData()) {
				polled_statii[ctrl].rawbits |= (1 << i);
			}
		}
		funDigitalWrite(clock, FUN_HIGH);
		Delay_Us(CONTROLLER_CLOCK_PERIOD_US/2);
		funDigitalWrite(clock, FUN_LOW);

		Delay_Us(CONTROLLER_CLOCK_PERIOD_US/2);
	}

	bool haveChanges = false;
	for (uint8_t ctrl=0; ctrl<CONTROLLERSET_NUM_CONTROLLERS; ctrl++) {
		if (controllers[ctrl].setStatus(polled_statii[ctrl])) {
			haveChanges = true;
			DEBUG_OUT("controller %u changed to %u\n", ctrl, polled_statii[ctrl].rawbits);

		}
	}


	return haveChanges;
}


const ControllerSet::StateBits & ControllerSet::state() {
	static StateBits rep = {0};

	static uint16_t controller_status_mask = 0;

	if (controller_status_mask == 0) {
		rep.num = CONTROLLER_STATUS_NUM_BITS_TO_REPORT*CONTROLLERSET_NUM_CONTROLLERS;
		for (uint8_t i=0; i< CONTROLLER_STATUS_NUM_BITS_TO_REPORT; i++) {
			controller_status_mask |= (1 << i);
		}
	}

	rep.state = 0;
	uint8_t numpresent = 0;
	bool present[CONTROLLERSET_NUM_CONTROLLERS];
	for (uint8_t ctrl=0; ctrl<CONTROLLERSET_NUM_CONTROLLERS; ctrl++) {
		rep.state |=  ( (controllers[ctrl].status().rawbits & controller_status_mask) << (ctrl*CONTROLLER_STATUS_NUM_BITS_TO_REPORT));
		present[ctrl] = controllers[ctrl].is_present();
		if (present[ctrl]) {
			numpresent++;
		}
	}
#ifdef REPORTER_SHIFT_SINGLE_CTRL_PRESENT_TO_LAST_BITS
#if CONTROLLERSET_NUM_CONTROLLERS > 1
	// Always send all bits, but move things around if necessary
	// rep.num = CONTROLLER_STATUS_NUM_BITS_TO_REPORT * (numpresent ? numpresent : 1);
	if (present[0] && ! present[1]) {
		// shift the bits around so controller 0 is sent last
		// in order to accomodate systems that only expect a
		// single controller and have only 12 flops to store data
		rep.state = (controllers[0].status().rawbits << (CONTROLLER_STATUS_NUM_BITS_TO_REPORT)) | controller_status_mask;
	}
#endif
#endif

	return rep;
}

} /* namespace SNES */

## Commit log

2025-01-21 TT default config specifications in doc, and support for TX LED blinks on input change
2025-01-29 600Hz polling and default IO pin set change.
2025-02-05 hardware project
    [GamepadPMOD.kicad_pcb, GamepadPMOD.kicad_sch]
2025-02-11 PCB v1.3: TT designed for logo, slightly larger drill for SFC conn
    [GamepadPMOD.kicad_pcb, GamepadPMOD.kicad_sch]
2025-03-26 Modified pmod, breaking 1U width to allow for 2 vertical SFC connectors
    [GamepadPMOD.kicad_pcb, GamepadPMOD.kicad_sch]
2025-03-26 kicad v9 migration
    [GamepadPMOD.kicad_sch]
2025-03-26 kicad v9 migration pII
    [GamepadPMOD.kicad_pcb]
2025-03-26 docs, sample upython, burning fw through RP2
    [gamepad_reader.py]
2026-07-27 Add Elecrow manufacturing files
    [GamepadPMOD-B_Cu.gbl, GamepadPMOD-B_Mask.gbs, GamepadPMOD-B_Paste.gbp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]
2026-07-27 Ignore KiCad temporary files
2026-07-29 Specify red status LED part
    [GamepadPMOD.kicad_pcb, GamepadPMOD.kicad_sch, GamepadPMOD_elecrow.xlsx]
2026-09-06 Add dual SNES connector gap filler
    Create a consolidated two-piece filler from the straight connector STEP geometry, add reproducible FreeCAD/KiCad assembly outputs, and wire the models into the Elecrow PCB for visual verification.
    [GamepadPMOD.kicad_pcb, GamepadPMOD_board.step, GamepadPMOD_dual_connector_assembly.FCStd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]
2026-09-06 Verify KiCad connector placement
    Regenerate the native KiCad renders with the corrected dual-filler transform and verify all fourteen STEP pin centres against the PCB drill coordinates.
    [GamepadPMOD_board.step, GamepadPMOD_dual_connector_assembly.FCStd, GamepadPMOD_dual_connector_assembly.step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]
2026-09-06 Strengthen dual connector filler bridge
    Extend the inter-connector bridge across the complete straight support section while retaining the two-piece post-assembly split.
    [GamepadPMOD_board.step, GamepadPMOD_dual_connector_assembly.FCStd, GamepadPMOD_dual_connector_assembly.step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]
2026-09-07 3D stabil. foot STL file
    [gamepad-footstabv1p0-tol2.stl]

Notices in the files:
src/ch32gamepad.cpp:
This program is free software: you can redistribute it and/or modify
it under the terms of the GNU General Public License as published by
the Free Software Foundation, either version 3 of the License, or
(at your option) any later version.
